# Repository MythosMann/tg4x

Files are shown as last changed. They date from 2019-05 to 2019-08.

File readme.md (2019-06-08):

Prototypes
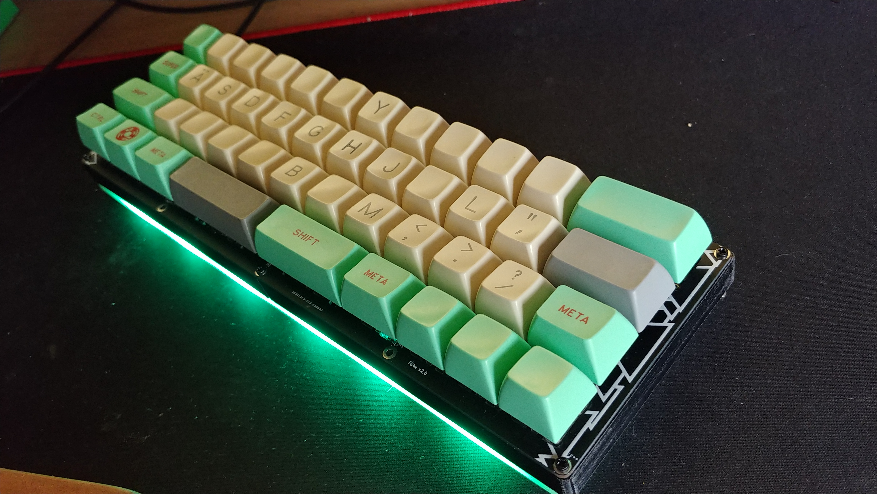
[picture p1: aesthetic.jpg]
3d printed midlayer and acrylic bottom

Picture of the Current Prototype
Nude
PCB
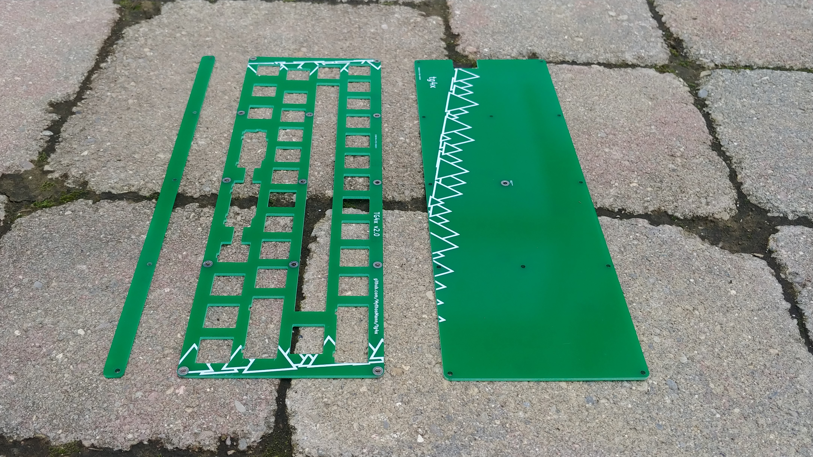
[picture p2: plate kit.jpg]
Plate Kit


Last gen prototype using tg3 as a base.
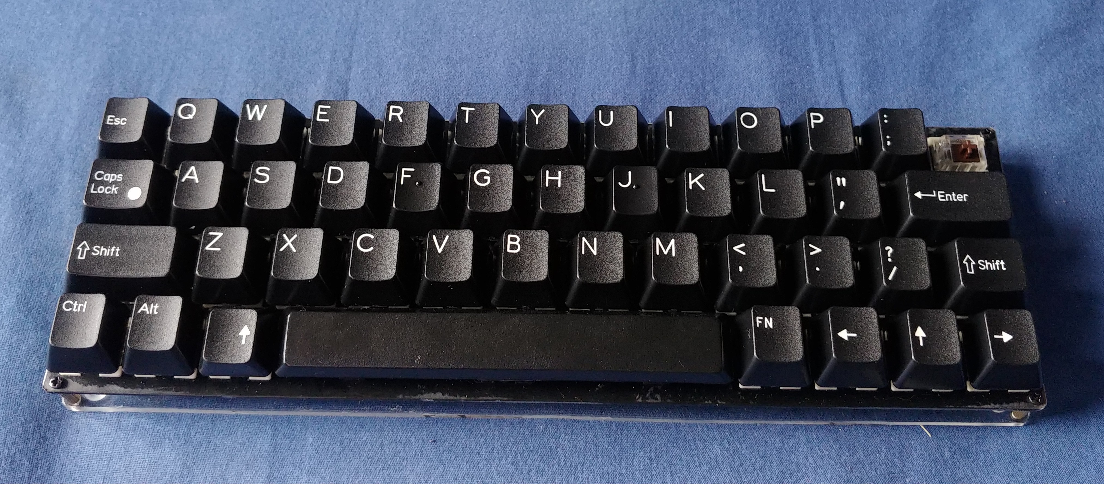
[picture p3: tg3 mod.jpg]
tg3 mod


## Summary:
Basically an open-source, cheap 45% keyboard.  You can use parts from a tg3 keyboard for maximum cheap, or use standard ansi keycaps.

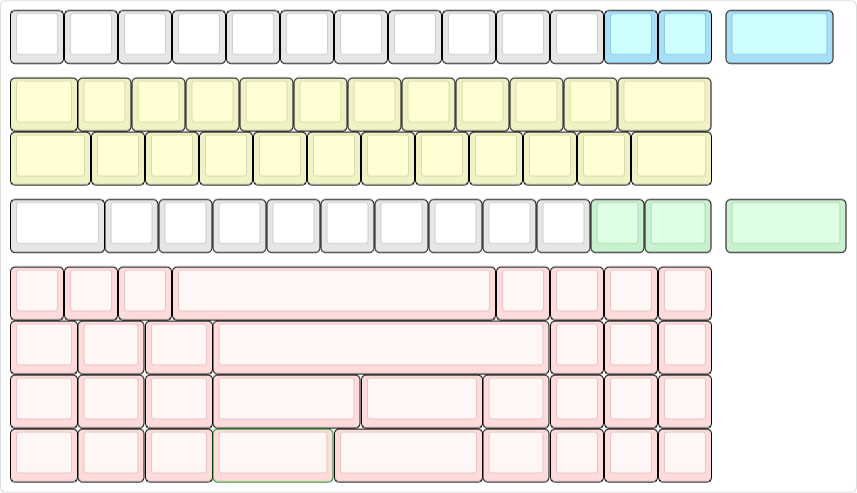
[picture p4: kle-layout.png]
KLE layout


## Features:
*Staggered 45%, meaning an extra column over standard 40%.

*Multiple supported layouts, including split spacebar.

*QMK compatible.

*Driven by pro micro, easily programmable and cheap.

*Uses standard sized keycaps that you could find in any set.

*RGB underglow, used for layer indication and caps lock.

*Design for pcb plates.

*Optional 6° angle.

## The base (TG3):
You can either use a tg3 as the base for this, or use your own parts.  The advantages of using the tg3 are price and sturdy-ness.  With a tg3, you can get Cherry blacks, uniform dcs keycaps, a steel mounting plate, and an aluminum back plate, all for $15-25.  If you were to buy the absolute cheapest keycap set ($6-8), the cheapest switches ($5 for 50), an fr4 or aluminum plate (~$10-15), and use a scrap of something for the back plate, it'd cost a bit more, and you'd be dealing with low quality parts. Granted, it takes some work to desolder and mod the tg3.

[Ebay listing where I've bought several](http://www.ebay.com/itm/132873035023)
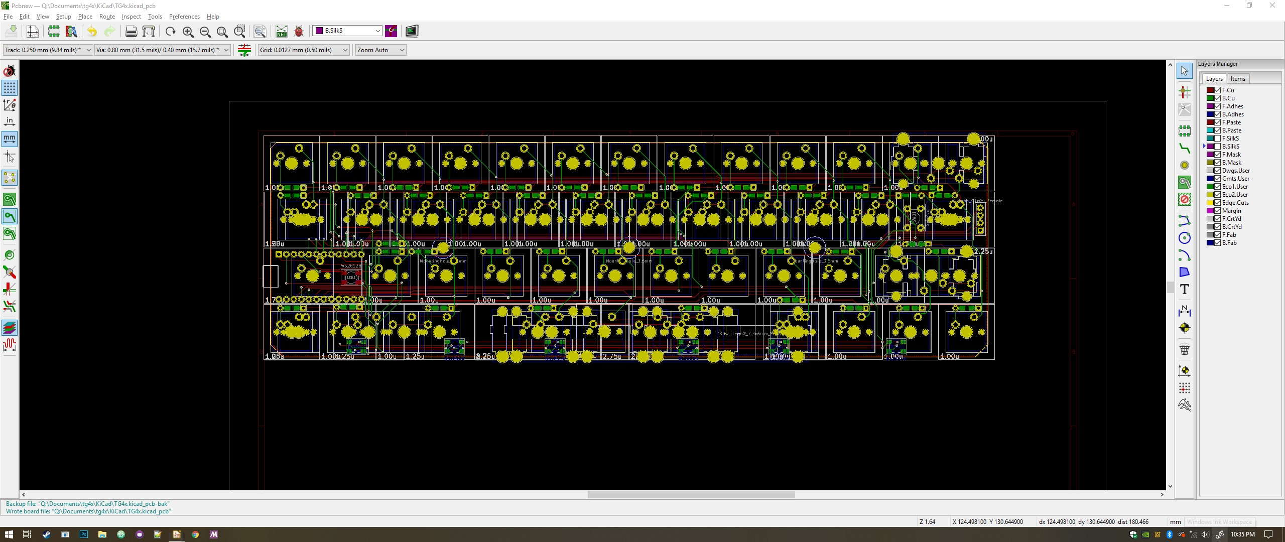
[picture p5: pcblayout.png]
Picture of the PCB


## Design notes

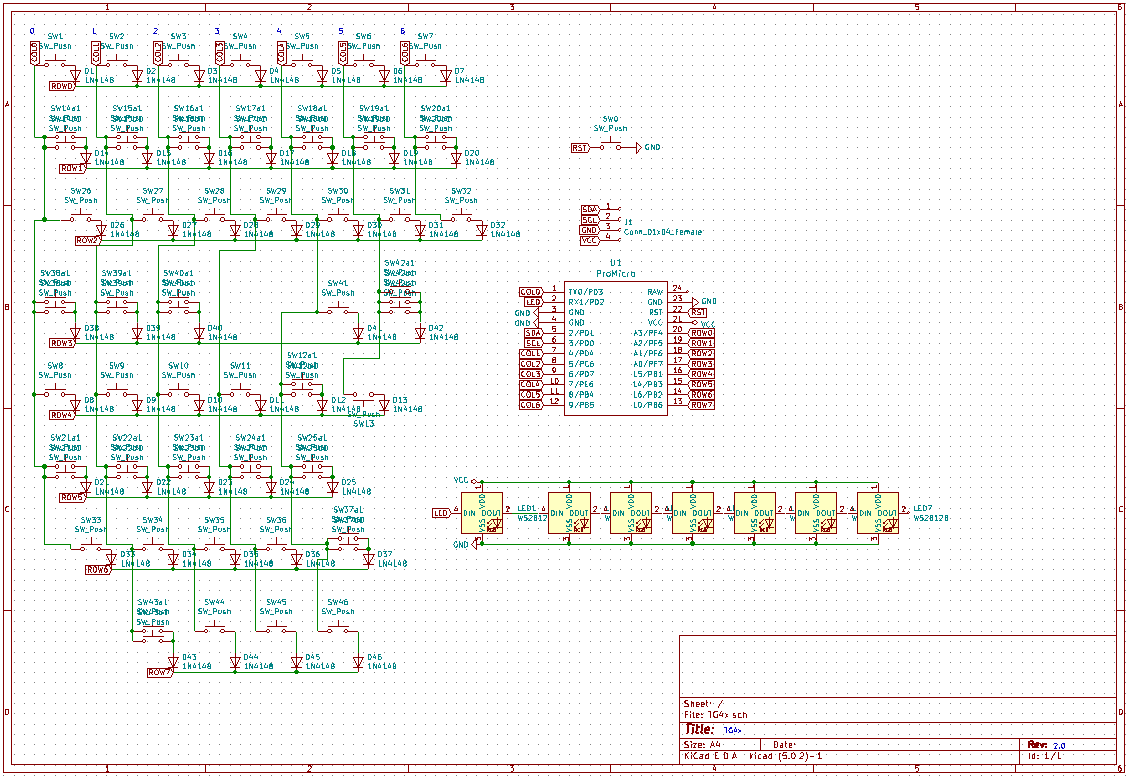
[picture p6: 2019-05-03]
Schematic.png

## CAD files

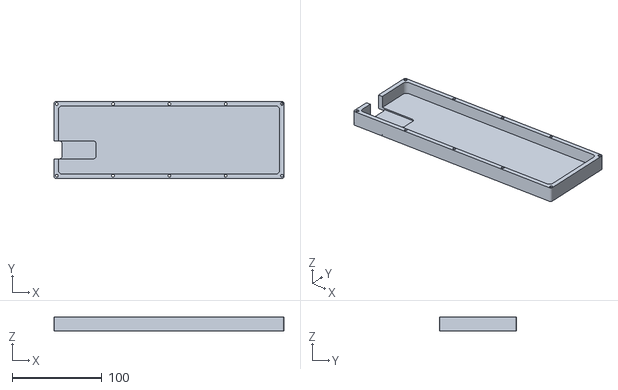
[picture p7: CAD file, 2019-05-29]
2d-3d stuff/tg4x case 3dp.stl
257.0 x 86.0 x 16.0

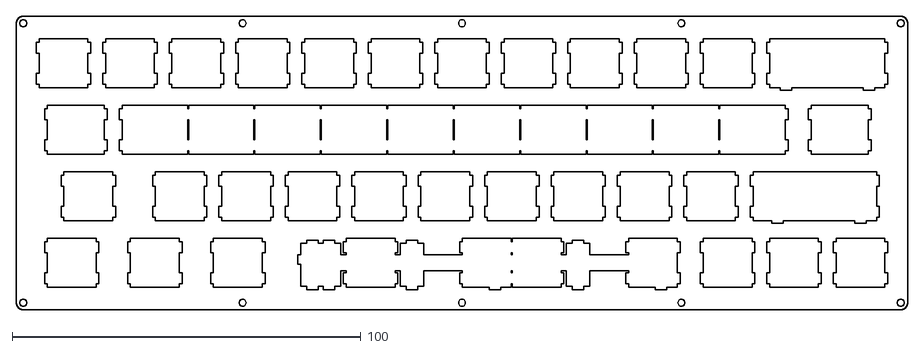
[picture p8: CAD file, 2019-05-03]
KiCad/switchplate.dxf
255.7 x 84.2

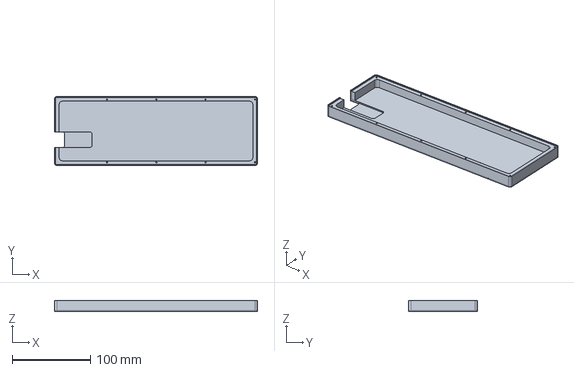
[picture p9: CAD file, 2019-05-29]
2d-3d stuff/tg4x case nomid.step
259.0 x 88.0 x 13.5 mm

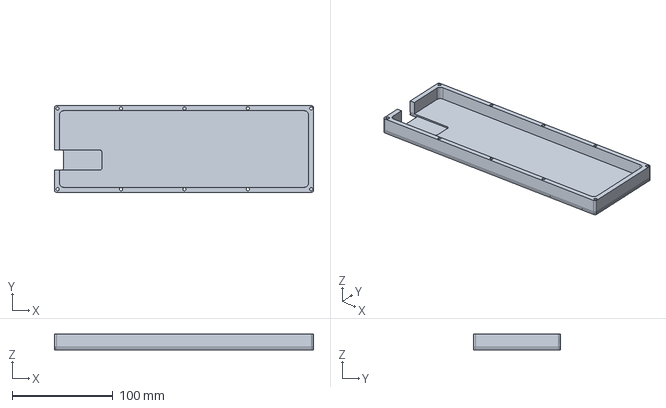
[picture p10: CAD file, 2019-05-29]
2d-3d stuff/tg4x_swillkb.step
257.0 x 86.0 x 15.5 mm

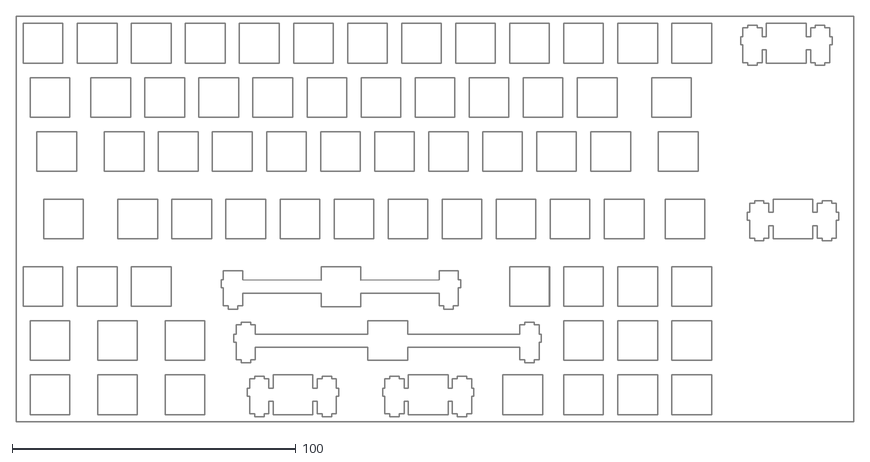
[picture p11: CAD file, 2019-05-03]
2d-3d stuff/tg4x_all_layout.dxf
295.3 x 142.9

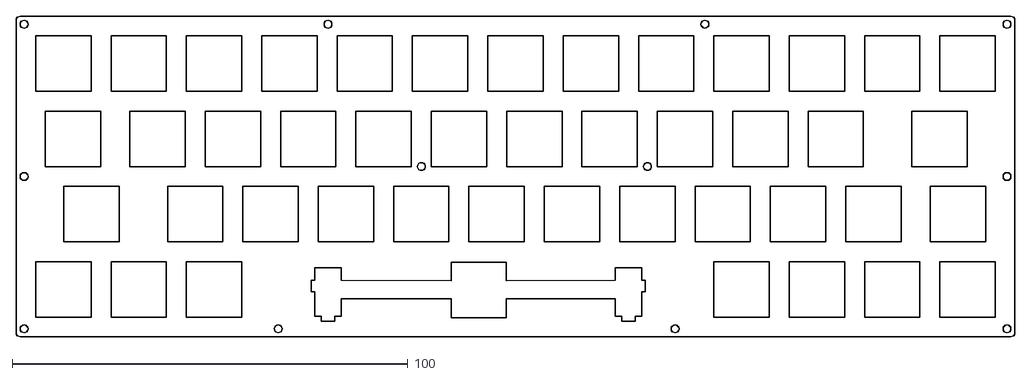
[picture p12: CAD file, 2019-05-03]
2d-3d stuff/switch_plate.dxf
252.5 x 81.0

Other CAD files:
2d-3d stuff/tg4x case.step
2d-3d stuff/tg4x case.stl
2d-3d stuff/tg4x_swillkb.stl

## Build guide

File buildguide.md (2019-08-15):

## Build Guide

Alrighty, so you got your tg4x stuff, but don’t know how to put it together.  I’ve finally gotten around to making this build guide, so now you’re covered.  Inside your box (depending on what you ordered), you should have 2 packages.
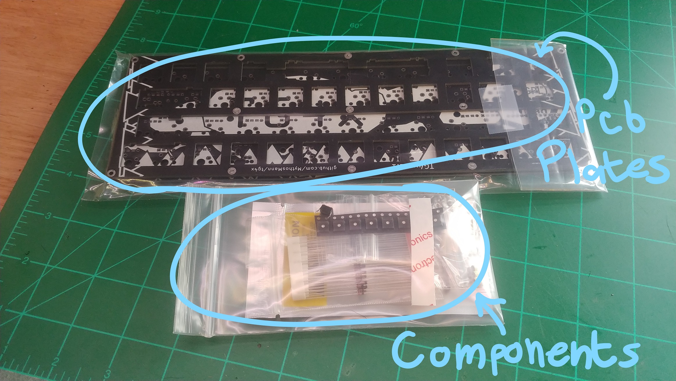
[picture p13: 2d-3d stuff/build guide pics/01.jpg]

One bag is the plates, and the pcb.  The other is your assembly kit, which contains all of the other pieces and components you need.
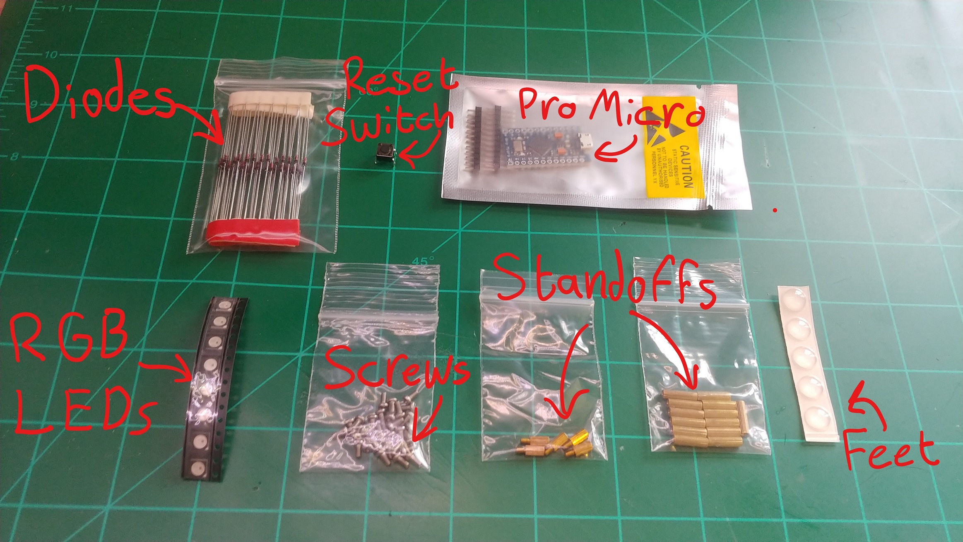
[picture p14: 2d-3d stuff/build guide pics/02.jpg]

Inside your assembly kit, you’ll find 50x diodes, a reset switch, a pro micro, 8x ws2812b rgb leds, ~28x screws, 5x 5mm male/female standoffs, 13x 11mm female/female standoffs, and some little rubber feet.
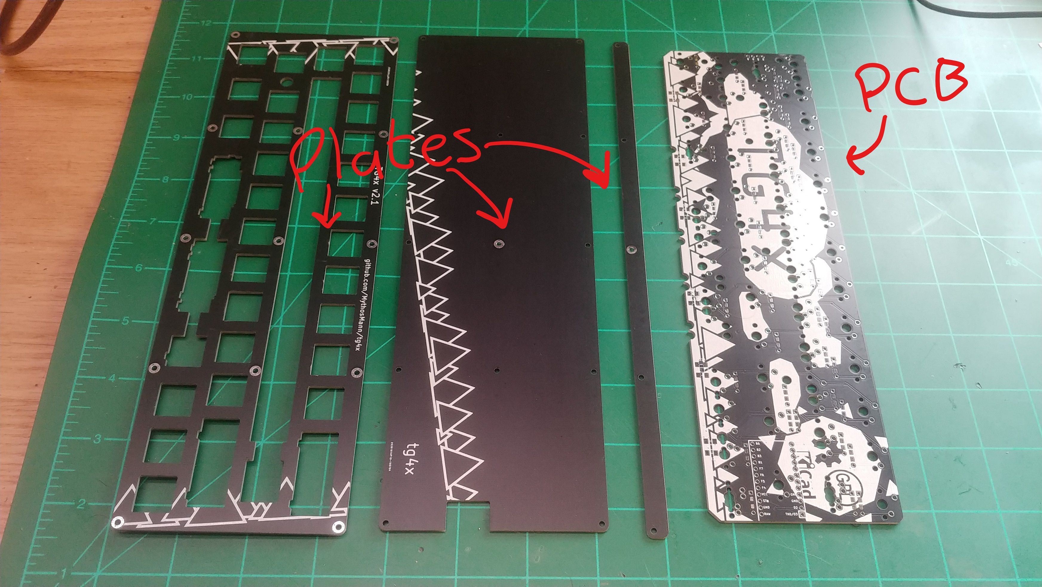
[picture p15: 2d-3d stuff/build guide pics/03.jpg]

In the other package, you’ll get a top plate, bottom plate, and a skinny little plate that you can use as a foot (to add a ~5 typing angle).  You’ll also get the pcb, where the magic happens.

 First thing you’ll want to do is bend all your diodes.  An easy way to do it consistently is to use your plates and pcb, put the diodes on top, and push all the legs down.  Then you’ve got to pull the paper off all the leads.  Next, you’re gonna put diodes in all of the diode holes.  It doesn’t matter if you put them on the top or bottom of the pcb, but make sure that they are oriented correctly.  You want the end with the black strip to go into the square holes.
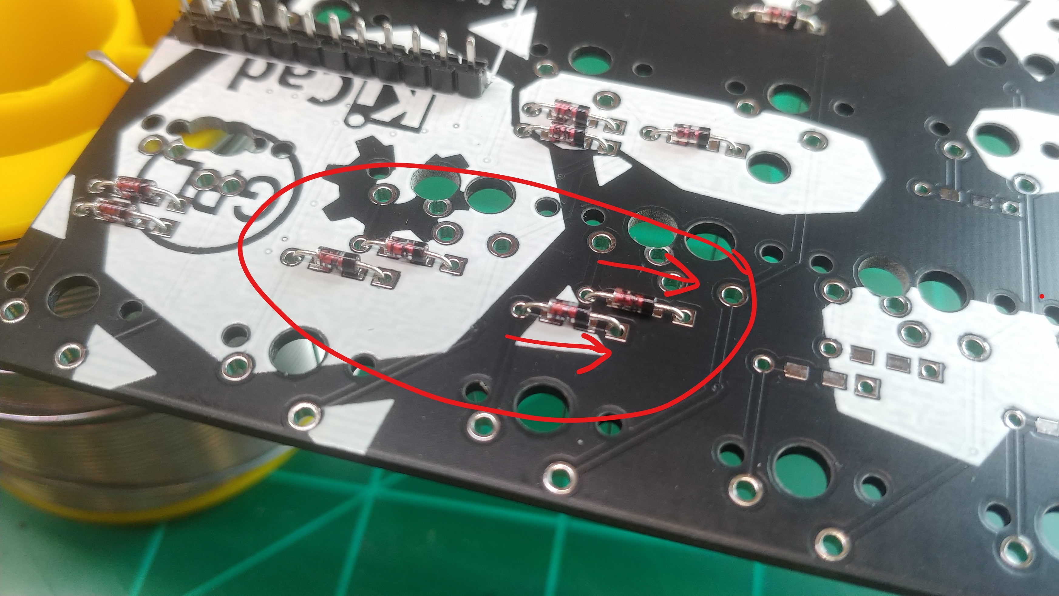
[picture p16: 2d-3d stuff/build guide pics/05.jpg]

The easiest way to install the diodes is to place them all in, then use masking tape to hold them in place.  Now you can flip the whole thing over, clip the legs off, and solder them all in.  I find it’s easier and looks cleaner if you clip the legs before soldering, but you could also solder first.
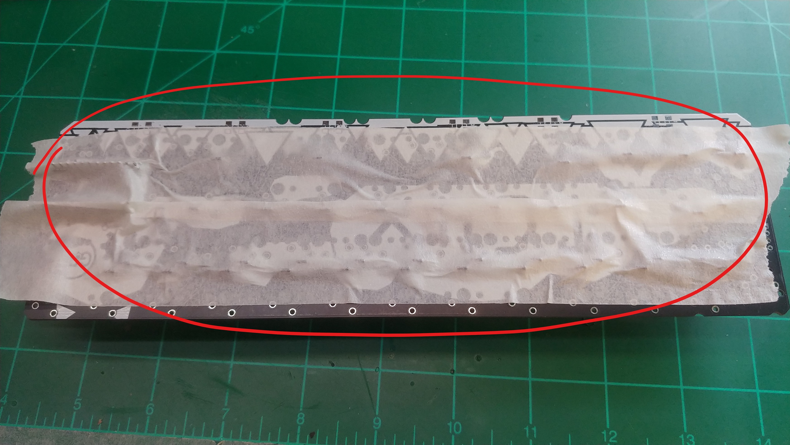
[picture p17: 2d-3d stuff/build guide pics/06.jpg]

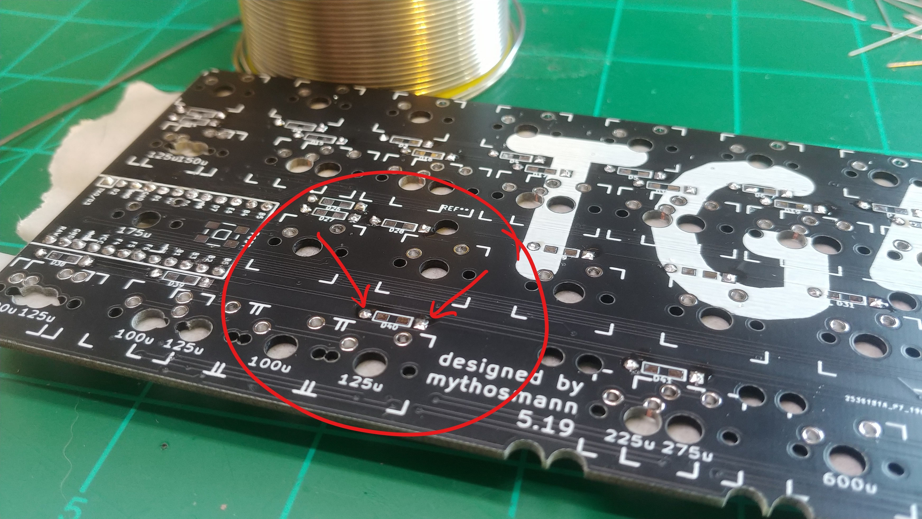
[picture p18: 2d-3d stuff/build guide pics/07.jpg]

Next, you want to solder in the headers for the pro micro.  You want them on the bottom of the pcb, which is the side with the big fancy graphic.  Don’t solder the pro micro on yet!  If you do, it’s gonna be really hard to solder the switches later.  I’d put the short end of the headers away from the pcb, with the long legs going through.  Then clip them flush with pcb.
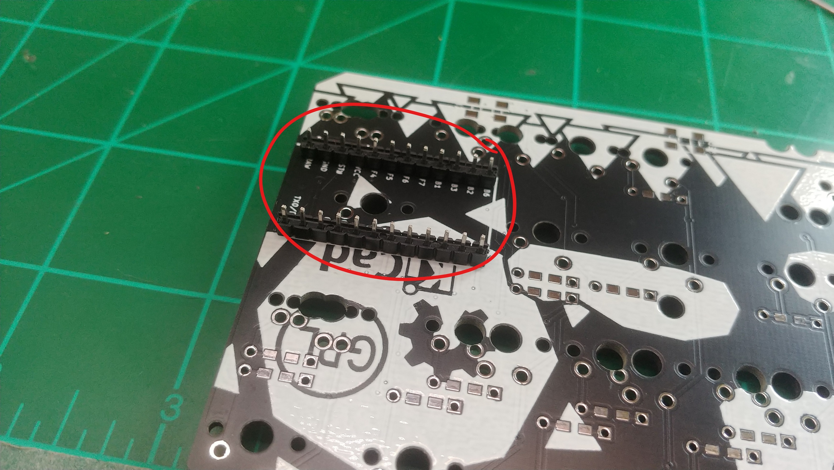
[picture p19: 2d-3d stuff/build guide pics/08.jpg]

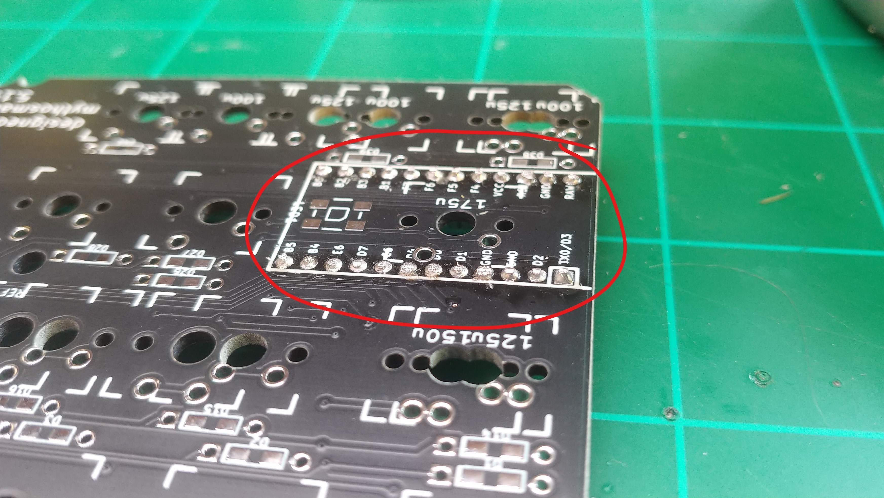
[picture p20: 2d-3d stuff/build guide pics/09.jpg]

Next, solder on the leds.  There’s one on the top of the pcb, and six on the bottom.  For the one on top, you want to make sure that the white corner is facing the left side of the pcb.  The leds on the bottom of the pcb all face down to the right, except for the one on the far right, which faces the other way.
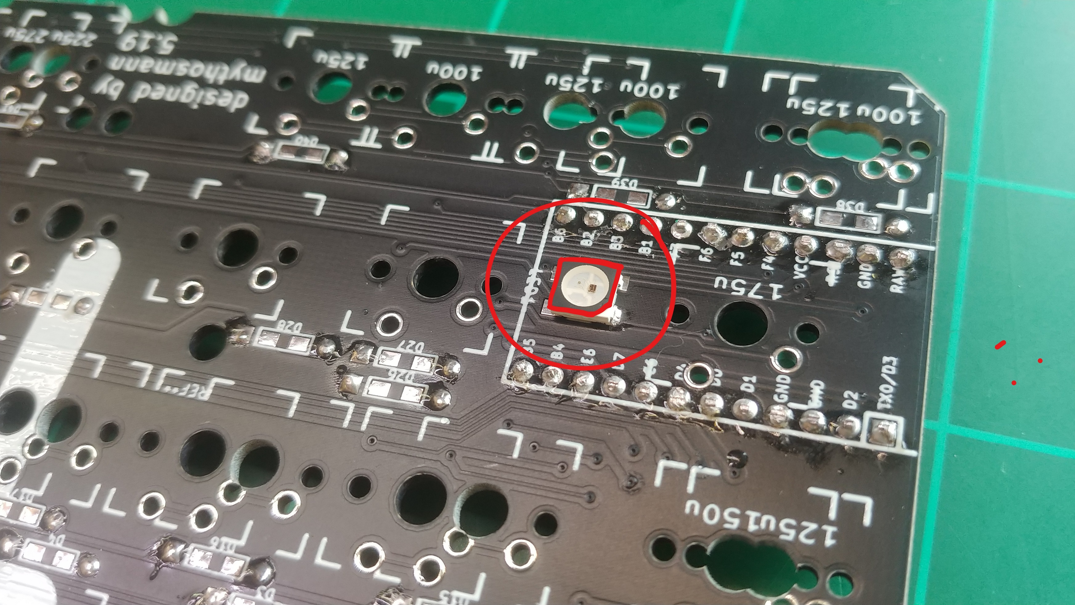
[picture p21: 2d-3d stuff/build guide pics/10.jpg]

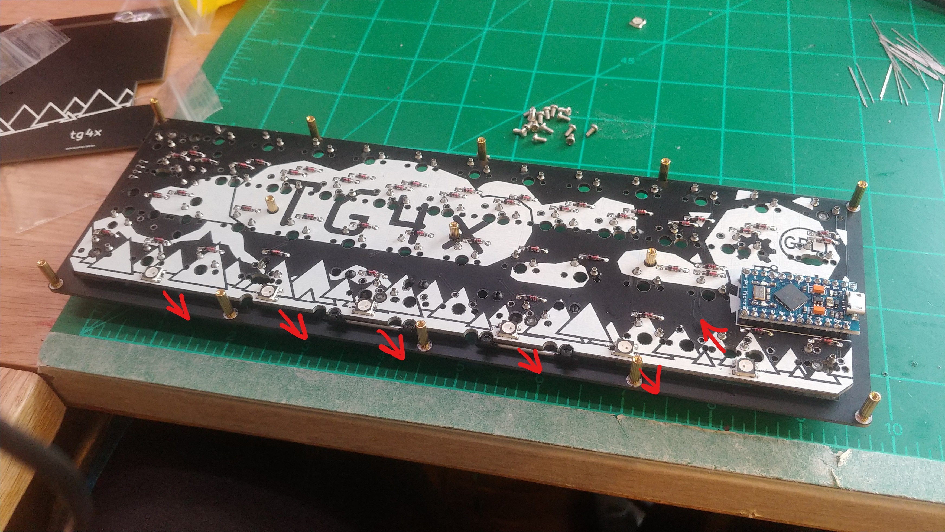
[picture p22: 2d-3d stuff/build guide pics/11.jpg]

If you have mill-max sockets, you’ll want to solder them in now.  I solder them just like diodes, so I’ll put them all in, tape over them, then solder them from the underside.
If you don’t have the sockets, skip over this step.
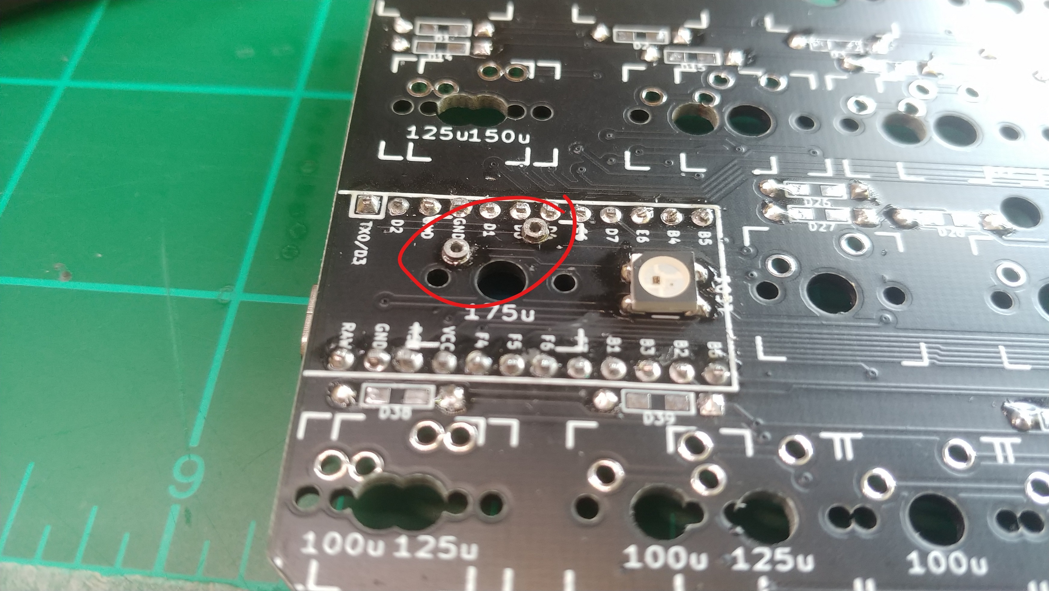
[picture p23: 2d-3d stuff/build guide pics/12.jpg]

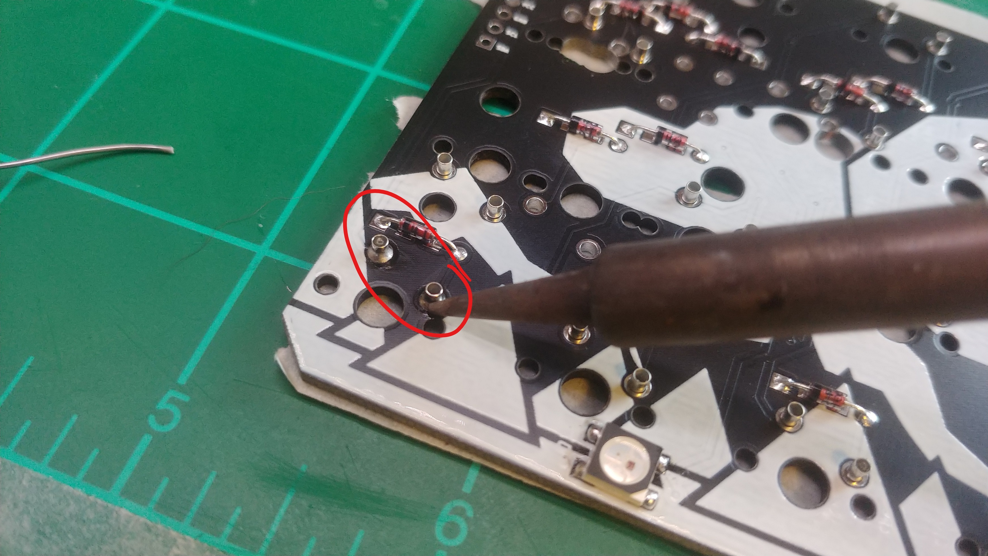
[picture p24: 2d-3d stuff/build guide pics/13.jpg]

Make sure you put the stabilizers in before you start to add the switches.  Put switches in each of the corners of the top plate, then fit it into the pcb.  I also like to put switches where the stabs are.  Solder those switches into the pcb.  Now it’ll be easier to fit the rest of the switches in, and solder them.  Of course, if you’re using mill-max sockets, there’s no need to solder the switches.
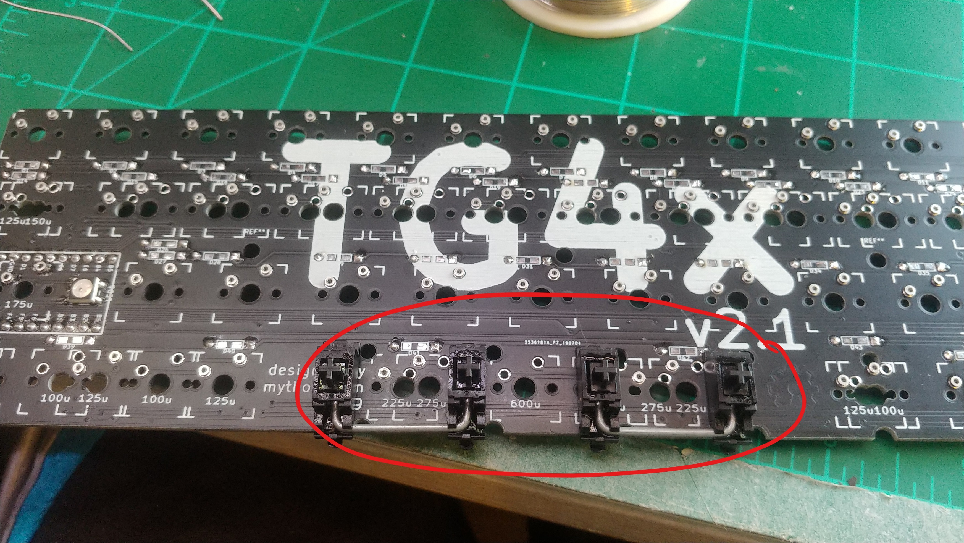
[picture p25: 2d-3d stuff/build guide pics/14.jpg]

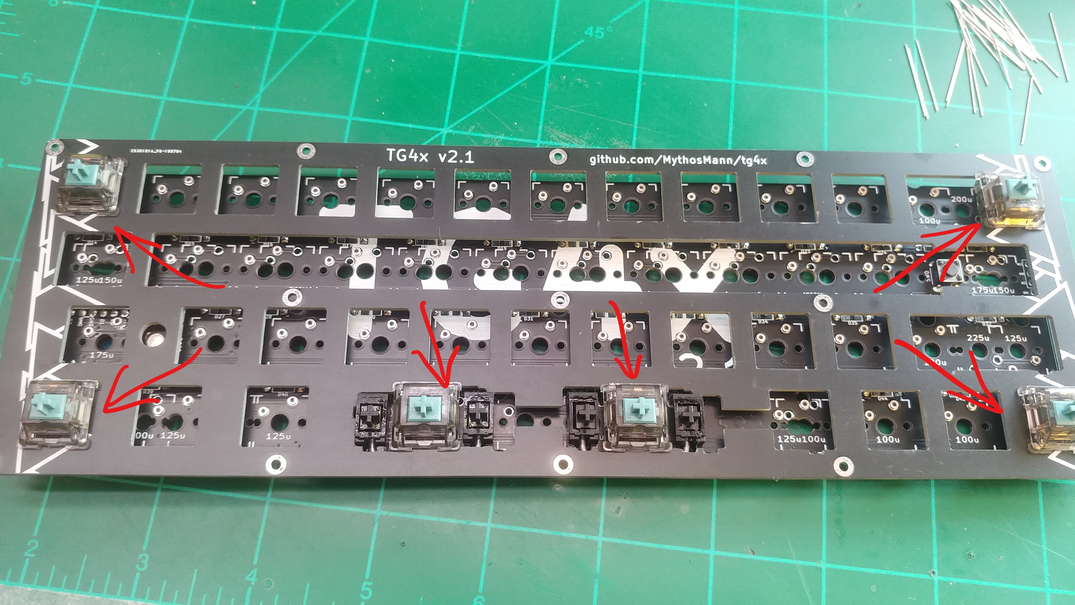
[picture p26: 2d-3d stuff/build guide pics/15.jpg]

After you’ve got all the switches installed, screw in all of the standoffs to the top plate.  There are 13 in total.  Put the bottom plate on, and screw it down.
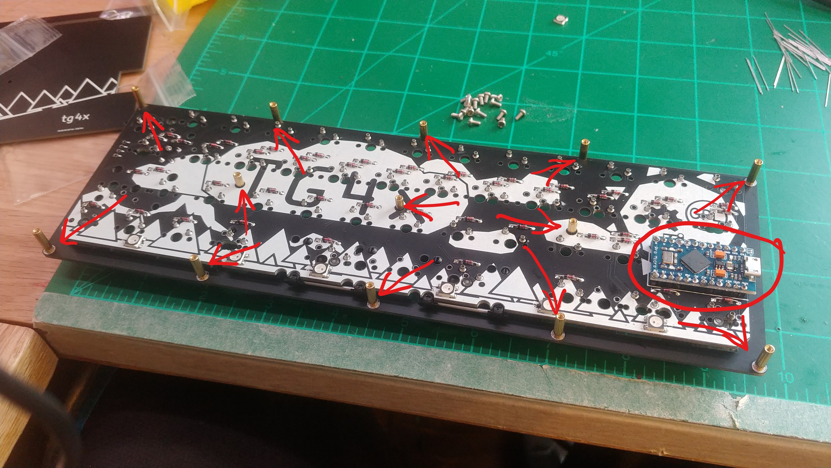
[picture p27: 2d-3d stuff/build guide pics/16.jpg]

If you want a bit of angle, use the 5mm standoffs in place of the screws on the top row.  Then, put the small plate on, and screw it in.
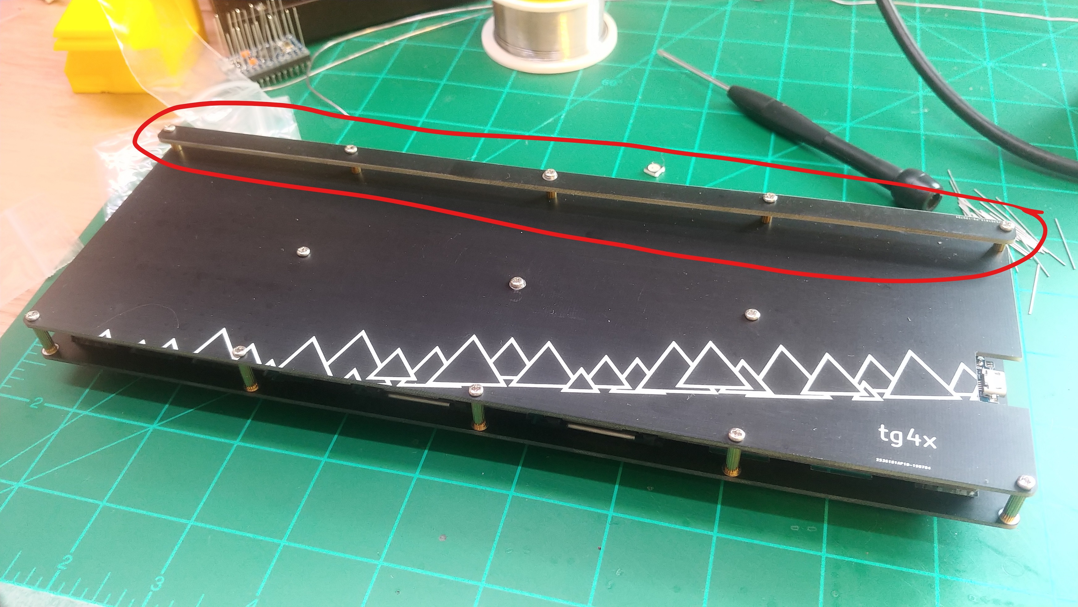
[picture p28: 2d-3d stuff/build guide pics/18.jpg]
 
Now all you’ve got to do is stick on some rubber feet, and find your keycaps.
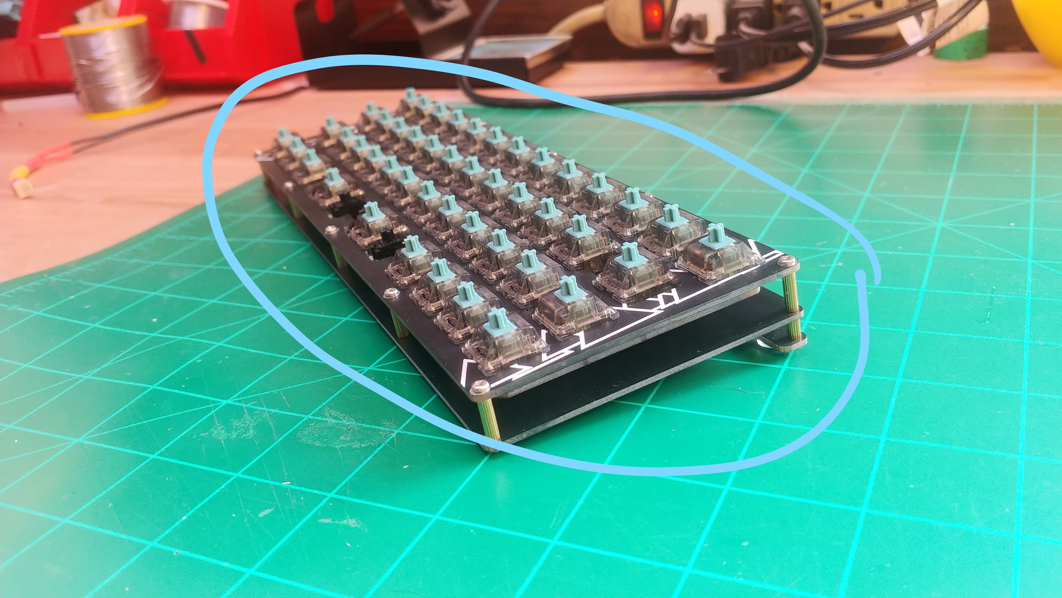
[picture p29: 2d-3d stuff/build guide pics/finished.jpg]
finished


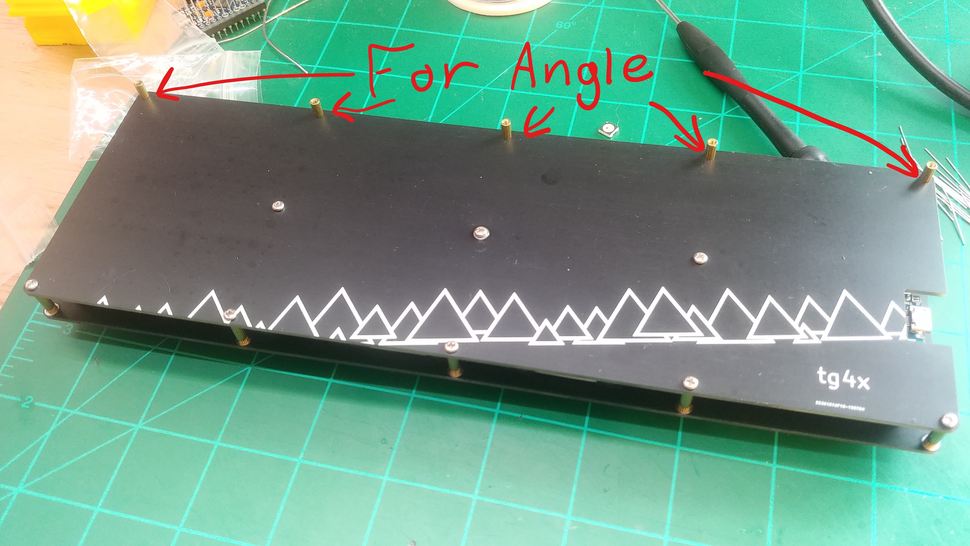
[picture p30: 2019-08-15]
2d-3d stuff/build guide pics/17.jpg

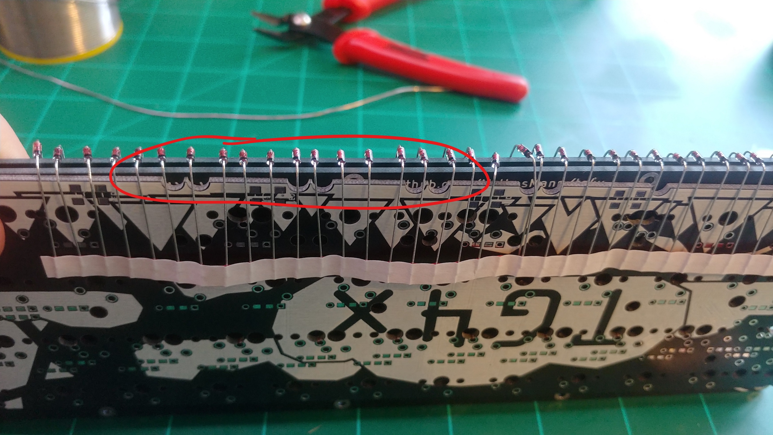
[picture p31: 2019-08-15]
2d-3d stuff/build guide pics/04.jpg

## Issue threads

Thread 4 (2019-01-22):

Footprint too big

MythosMann, 2019-01-22:

Closed 2019-01-23.

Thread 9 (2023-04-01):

Error when compiling qmk

sunmorgus, 2023-04-01:
I'm getting all sorts of errors when attempting to compile changes to QMK, and seem to have gotten the keyboard set back to some sort of default that just doesn't have keys mapped properly at _all_... below is the error message I get when attempting to compile:

What I've done:
1. Setup qmk properly (it works just fine for my Keychron V8)
1. Cloned the `tg4x` folder from the `qmk_firmware/keyboards` directory, and copied the `qmk_firmware/keyboards/tg4x` over to my `qmk_firmware/keyboards` home
2. Run both `qmk compile -kb tg4x -km default` and `make tg4x/rev21:default` and got the below errors

**Running qmk compile**
```
➜  ~/qmk_firmware git:(master) ✗ qmk compile -kb tg4x -km default
Ψ Compiling keymap with gmake --jobs=1 tg4x:default

QMK Firmware 0.20.3
☒ tg4x: Layout "LAYOUT" has no "matrix" definition in either "info.json" or "<keyboard>.h"!
☒ 'matrix_size'
Traceback (most recent call last):
  File "/home/sunmorgus/.local/lib/python3.10/site-packages/milc/milc.py", line 528, in __call__
    return self.__call__()
  File "/home/sunmorgus/.local/lib/python3.10/site-packages/milc/milc.py", line 533, in __call__
    return self._subcommand(self)
  File "/home/sunmorgus/qmk_firmware/lib/python/qmk/decorators.py", line 27, in wrapper
    return func(*args, **kwargs)
  File "/home/sunmorgus/qmk_firmware/lib/python/qmk/cli/list/layouts.py", line 21, in list_layouts
    info_data = info_json(cli.config.list_layouts.keyboard)
  File "/home/sunmorgus/qmk_firmware/lib/python/qmk/info.py", line 148, in info_json
    info_data = _extract_led_config(info_data, str(keyboard))
  File "/home/sunmorgus/qmk_firmware/lib/python/qmk/info.py", line 670, in _extract_led_config
    cols = info_data['matrix_size']['cols']
KeyError: 'matrix_size'
Making tg4x with keymap default

☒ tg4x: Layout "LAYOUT" has no "matrix" definition in either "info.json" or "<keyboard>.h"!
☒ 'matrix_size'
Traceback (most recent call last):
  File "/home/sunmorgus/.local/lib/python3.10/site-packages/milc/milc.py", line 528, in __call__
    return self.__call__()
  File "/home/sunmorgus/.local/lib/python3.10/site-packages/milc/milc.py", line 533, in __call__
    return self._subcommand(self)
  File "/home/sunmorgus/qmk_firmware/lib/python/qmk/cli/generate/rules_mk.py", line 59, in generate_rules_mk
    kb_info_json = dotty(info_json(cli.args.keyboard))
  File "/home/sunmorgus/qmk_firmware/lib/python/qmk/info.py", line 148, in info_json
    info_data = _extract_led_config(info_data, str(keyboard))
  File "/home/sunmorgus/qmk_firmware/lib/python/qmk/info.py", line 670, in _extract_led_config
    cols = info_data['matrix_size']['cols']
KeyError: 'matrix_size'

 *                                                                                                     [ERRORS]

builddefs/build_keyboard.mk:196: *** Platform not defined.  Stop.
Make finished with errors
gmake: *** [Makefile:392: tg4x:default] Error 1

```

**Running make**
```
➜  ~/qmk_firmware git:(master) ✗ make tg4x/rev21:default
QMK Firmware 0.20.3
☒ tg4x/rev21: Layout "LAYOUT" has no "matrix" definition in either "info.json" or "<keyboard>.h"!
☒ tg4x/rev21: DESCRIPTION in config.h is no longer a valid option and should be removed
☒ tg4x/rev21: DEBOUNCING_DELAY in config.h is no longer a valid option and should be replaced with DEBOUNCE
⚠ tg4x/rev21: UNUSED_PINS in config.h is deprecated and will be removed at a later date
⚠ tg4x/rev21: PRODUCT_ID in config.h is deprecated in favor of `usb.pid` in info.json and will be removed at a later date
⚠ tg4x/rev21: VENDOR_ID in config.h is deprecated in favor of `usb.vid` in info.json and will be removed at a later date
⚠ tg4x/rev21: PRODUCT in config.h is deprecated in favor of `keyboard_name` in info.json and will be removed at a later date
⚠ tg4x/rev21: MANUFACTURER in config.h is deprecated in favor of `manufacturer` in info.json and will be removed at a later date
⚠ tg4x/rev21: DEVICE_VER in config.h is deprecated in favor of `usb.device_version` in info.json and will be removed at a later date
☒ Invalid API data: tg4x/rev21: layouts: 'LAYOUT_TG3' is not valid under any of the given schemas
Making tg4x/rev21 with keymap default

☒ tg4x/rev21: Layout "LAYOUT" has no "matrix" definition in either "info.json" or "<keyboard>.h"!
☒ tg4x/rev21: DESCRIPTION in config.h is no longer a valid option and should be removed
☒ tg4x/rev21: DEBOUNCING_DELAY in config.h is no longer a valid option and should be replaced with DEBOUNCE
⚠ tg4x/rev21: UNUSED_PINS in config.h is deprecated and will be removed at a later date
⚠ tg4x/rev21: PRODUCT_ID in config.h is deprecated in favor of `usb.pid` in info.json and will be removed at a later date
⚠ tg4x/rev21: VENDOR_ID in config.h is deprecated in favor of `usb.vid` in info.json and will be removed at a later date
⚠ tg4x/rev21: PRODUCT in config.h is deprecated in favor of `keyboard_name` in info.json and will be removed at a later date
⚠ tg4x/rev21: MANUFACTURER in config.h is deprecated in favor of `manufacturer` in info.json and will be removed at a later date
⚠ tg4x/rev21: DEVICE_VER in config.h is deprecated in favor of `usb.device_version` in info.json and will be removed at a later date
☒ Invalid API data: tg4x/rev21: layouts: 'LAYOUT_TG3' is not valid under any of the given schemas

 *                                                                                                     [ERRORS]

builddefs/build_keyboard.mk:196: *** Platform not defined.  Stop.
Make finished with errors
make: *** [Makefile:392: tg4x/rev21:default] Error 1
```

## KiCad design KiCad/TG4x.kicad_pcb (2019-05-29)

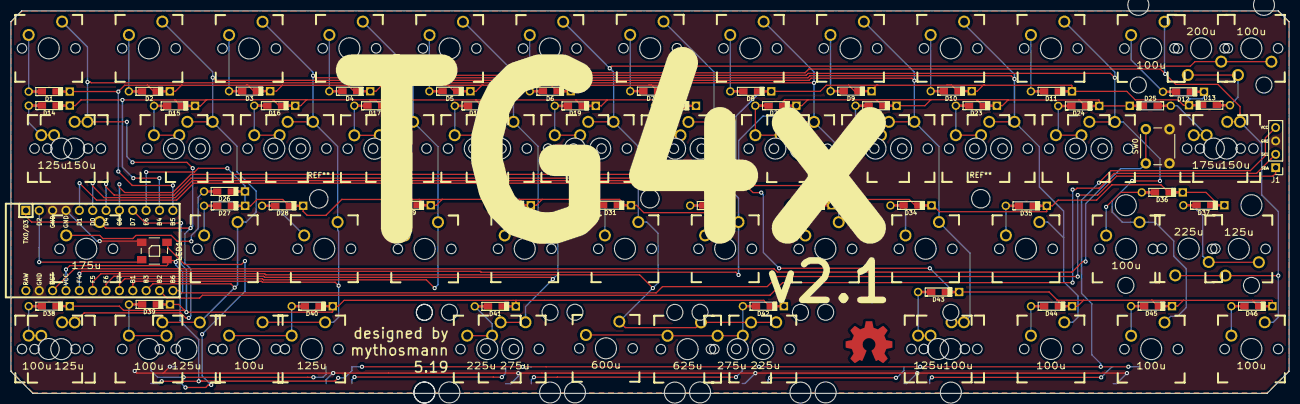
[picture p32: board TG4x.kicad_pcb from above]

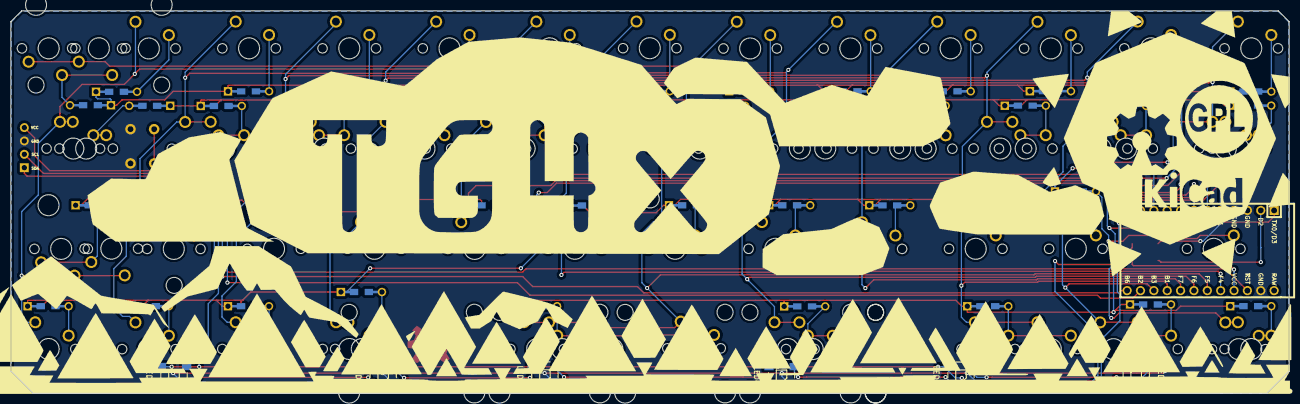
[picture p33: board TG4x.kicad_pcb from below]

Board: 2 copper layers, 243.0 x 72.7 mm, 124 parts (7 on the bottom side), 73 nets.

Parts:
100u, 100u#2, 100u#3, 100u#4, 100u#5, 100u#6, 100u#7, 100u#8, 100u#9, 100u#10, 125u, 600u: SW_Push; MX_PCB_100H
125u#2, 125u#3, 125u#4, 125u#5, 125u#6: SW_Push; MX_PCB_125H
150u, 175u#2: SW_Push; MX_PCB_150H
150u#2, 175u: SW_Push; MX_PCB_175H
200u: SW_Push; MX_PCB_200H
225u, 225u#2, 225u#3: SW_Push; MX_PCB_225H
275u, 275u#2: SW_Push; MX_PCB_275H
625u: SW_Push; MX_PCB_625H
D1, D2, D3, D4, D5, D6, D7, D8, D9, D10, D11, D12, D13, D14, D15, D16, D17, D18, D19, D20, D21, D22, D23, D24, D25, D26, D27, D28, D29, D30, D31, D32, D33, D34, D35, D36, D37, D38, D39, D40, D41, D42, D43, D44, D45, D46: 1N4148; Diode-dual
J1: Conn_01x04_Female; PinHeader_1x04_P2.54mm_Vertical
LED1, LED2, LED3, LED4, LED5, LED6, LED7: WS2812B
SW0: SW_Push; SW_PUSH_6mm
SW1, SW2, SW3, SW4, SW5, SW6, SW7, SW8, SW9, SW10, SW11, SW15, SW15b1, SW16, SW16b1, SW17, SW17b1, SW18, SW18b1, SW19, SW19b1, SW20, SW20b1, SW21, SW21b1, SW22, SW22b1, SW23, SW23b1, SW24, SW24b1, SW27, SW28, SW29, SW30, SW31, SW32, SW33, SW34, SW35: SW_Push; MX_PCB_100H
U1: ProMicro; ArduinoProMicro

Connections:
COL0: 100u#6.1, 125u#2.1, 125u#4.1, 150u.1, 175u.1, SW1.1, SW8.1, SW21.1, SW21b1.1, SW33.1, U1.1
COL1: 100u#7.1, 100u#9.1, 125u.1, 125u#5.1, SW2.1, SW9.1, SW15.1, SW15b1.1, SW22.1, SW22b1.1, SW27.1, SW34.1, U1.15
COL2: 100u#2.1, 100u#8.1, 125u#6.1, SW3.1, SW10.1, SW16.1, SW16b1.1, SW23.1, SW23b1.1, SW28.1, SW35.1, U1.16
COL3: 100u.1, 100u#3.1, SW4.1, SW11.1, SW17.1, SW17b1.1, SW24.1, SW24b1.1, SW29.1, U1.17
COL4: 100u#4.1, 100u#5.1, 125u#3.1, 150u#2.1, 175u#2.1, 225u.1, 225u#2.1, 275u#2.1, SW5.1, SW18.1, SW18b1.1, SW30.1, U1.18
COL5: 100u#10.2, 200u.2, 225u#3.1, 275u.1, 600u.1, 625u.1, SW6.1, SW19.1, SW19b1.1, SW31.1, U1.19
COL6: SW7.1, SW20.1, SW20b1.1, SW32.1, U1.20
GND: J1.3, LED1.3, LED2.3, LED3.3, LED4.3, LED5.3, LED6.3, LED7.3, SW0.2, U1.3, U1.4, U1.23
LED: LED1.4, U1.2
unnamed: D1.2, SW1.2
unnamed: D2.2, SW2.2
unnamed: D3.2, SW3.2
unnamed: D4.2, SW4.2
unnamed: D5.2, SW5.2
unnamed: D6.2, SW6.2
unnamed: D7.2, SW7.2
unnamed: D8.2, SW8.2
unnamed: D9.2, SW9.2
unnamed: D10.2, SW10.2
unnamed: D11.2, SW11.2
unnamed: 100u#5.2, D12.2
unnamed: 100u#10.1, 200u.1, D13.2
unnamed: 125u#2.2, 150u.2, D14.2
unnamed: D15.2, SW15.2, SW15b1.2
unnamed: D16.2, SW16.2, SW16b1.2
unnamed: D17.2, SW17.2, SW17b1.2
unnamed: D18.2, SW18.2, SW18b1.2
unnamed: D19.2, SW19.2, SW19b1.2
unnamed: D20.2, SW20.2, SW20b1.2
unnamed: D21.2, SW21.2, SW21b1.2
unnamed: D22.2, SW22.2, SW22b1.2
unnamed: D23.2, SW23.2, SW23b1.2
unnamed: D24.2, SW24.2, SW24b1.2
unnamed: 150u#2.2, 175u#2.2, D25.2
unnamed: 175u.2, D26.2
unnamed: D27.2, SW27.2
unnamed: D28.2, SW28.2
unnamed: D29.2, SW29.2
unnamed: D30.2, SW30.2
unnamed: D31.2, SW31.2
unnamed: D32.2, SW32.2
unnamed: D33.2, SW33.2
unnamed: D34.2, SW34.2
unnamed: D35.2, SW35.2
unnamed: 100u.2, D36.2
unnamed: 125u#3.2, 225u.2, D37.2
unnamed: 100u#6.2, 125u#4.2, D38.2
unnamed: 100u#7.2, 125u#5.2, D39.2
unnamed: 100u#8.2, 125u#6.2, D40.2
unnamed: 225u#2.2, 275u#2.2, D41.2
unnamed: 225u#3.2, 275u.2, 600u.2, 625u.2, D42.2
unnamed: 100u#9.2, 125u.2, D43.2
unnamed: 100u#2.2, D44.2
unnamed: 100u#3.2, D45.2
unnamed: 100u#4.2, D46.2
unnamed: LED1.2, LED2.4
unnamed: LED2.2, LED3.4
unnamed: LED3.2, LED4.4
unnamed: LED4.2, LED5.4
unnamed: LED5.2, LED6.4
unnamed: LED6.2, LED7.4
ROW0: D1.1, D2.1, D3.1, D4.1, D5.1, D6.1, D7.1, U1.12
ROW1: D14.1, D15.1, D16.1, D17.1, D18.1, D19.1, D20.1, U1.11
ROW2: D26.1, D27.1, D28.1, D29.1, D30.1, D31.1, D32.1, U1.10
ROW3: D38.1, D39.1, D40.1, D41.1, D42.1, U1.9
ROW4: D8.1, D9.1, D10.1, D11.1, D12.1, D13.1, U1.8
ROW5: D21.1, D22.1, D23.1, D24.1, D25.1, U1.7
ROW6: D33.1, D34.1, D35.1, D36.1, D37.1, U1.6
ROW7: D43.1, D44.1, D45.1, D46.1, U1.5
RST: SW0.1, U1.22
SCL: J1.2, U1.14
SDA: J1.1, U1.13
VCC: J1.4, LED1.1, LED2.1, LED3.1, LED4.1, LED5.1, LED6.1, LED7.1, U1.21

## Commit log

2019-01-23 Added KiCad files for first revision.
    The KiCad Libraries, Schematic, pcb, and gerber files.
    [TG4x-B.Cu.gbl, TG4x-B.Mask.gbs, TG4x-B.SilkS.gbo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]
2019-01-23 organized all files together
    Put everything together locally, hopefully made things more organized.
    [TG4x-B.Cu.gbl, TG4x-B.Mask.gbs, TG4x-B.Paste.gbp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]
2019-01-23 Trying to organize lol
    [TG4x-B.Cu.gbl, TG4x-B.Mask.gbs, TG4x-B.Paste.gbp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]
2019-01-23 Shifted some diode footprints
    [TG4x.kicad_pcb]
2019-01-23 removed LED Sleep
2019-01-24 Update Pro micro footprint
    Now uses keebio's staggered footprint
    [TG4x.kicad_pcb, TG4x.sch]
2019-01-24 Changed image files
    [TG4x.kicad_pcb]
2019-01-25 Added .dxf and .ai for plates
    [bottom_plate.dxf, switch_plate.dxf]
2019-01-25 Added middle standoff holes
    [TG4x.kicad_pcb, bottom_plate.dxf, switch_plate.dxf]
2019-01-27 fixed mouting holes
    [TG4x-B.Cu.gbl, TG4x-B.Mask.gbs, TG4x-B.SilkS.gbo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]
2019-01-29 added silkscreen
    [TG4x.kicad_pcb]
2019-01-29 added mounting holes, fixed traces, updated gerbers
    [TG4x-B.Cu.gbl, TG4x-B.Mask.gbs, TG4x-B.SilkS.gbo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]
2019-01-29 Adding Tap Dance Support to qmk files.
    [TG4x.kicad_pcb]
2019-01-29 updated keymap, re-enabled LEDs
2019-01-29 updated pcb graphic
    [TG4x.kicad_pcb]
2019-01-29 pcb graphics
    [TG4x.kicad_pcb]
2019-01-29 changed thumbs
    [TG4x.kicad_pcb]
2019-01-30 updated gerbers, switch plate files
    [TG4x-B.Cu.gbl, TG4x-B.Mask.gbs, TG4x-B.SilkS.gbo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]
2019-01-30 new render, updated case files
2019-02-01 changed footprints to 5 pin
    [TG4x.kicad_pcb]
2019-02-01 Fixed traces for 5 pin
    [TG4x.kicad_pcb]
2019-02-01 Updated gerbers for 5 pin
    [TG4x-B.Cu.gbl, TG4x-B.Mask.gbs, TG4x-B.SilkS.gbo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]
2019-02-05 Fixed traces, leds
    moved some of the traces that were too close to holes, moved leds out from under holes
    [TG4x.kicad_pcb]
2019-02-06 updated to staggered pro micro footprint
    [TG4x.kicad_pcb]
2019-02-08 moved spacebar switch footprint
    [TG4x.kicad_pcb, bottom_plate.dxf, switch_plate.dxf]
2019-02-08 moved left hand diodes in
    [TG4x.kicad_pcb]
2019-02-08 added clearance for standoffs
    [TG4x.kicad_pcb, switch_plate.dxf]
2019-02-08 finished adding standoff clearance
    [TG4x.kicad_pcb]
2019-02-09 Changing pcb Graphic
    [TG4x-B.Cu.gbl, TG4x-B.Mask.gbs, TG4x-B.SilkS.gbo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]
2019-02-09 Organized image files, finished graphic
    [TG4x-B.Cu.gbl, TG4x-B.Mask.gbs, TG4x-B.SilkS.gbo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]
2019-02-10 Fixed LED Polaarity, uppdated to v1.2
    [TG4x.kicad_pcb, TG4x.sch]
2019-02-11 Updated graphic and thummbnails
    [TG4x.kicad_pcb, TG4x.sch]
2019-02-11 slightly changed edge cut
    [TG4x-B.Cu.gbl, TG4x-B.Mask.gbs, TG4x-B.SilkS.gbo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]
2019-02-19 trimmed top and bottom.
    [TG4x.kicad_pcb]
2019-02-19 scaled graphic to new pcb
    [TG4x.kicad_pcb]
2019-02-19 Update PCB_forest graphic.psd
2019-02-19 shrunk column labelling
    [TG4x.kicad_pcb]
2019-02-19 removed switch labels from f.silk
    [TG4x.kicad_pcb]
2019-02-24 updated gerber files
    [TG4x-B.Cu.gbl, TG4x-B.Mask.gbs, TG4x-B.SilkS.gbo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]
2019-02-24 updated gerbers, started on platge stencil
    [TG4x-B.Cu.gbl, TG4x-B.Mask.gbs, TG4x-B.SilkS.gbo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]
2019-02-24 gerbers again
    [TG4x-B.Cu.gbl, TG4x-B.Mask.gbs, TG4x-B.SilkS.gbo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]
2019-02-24 changed gerber settings
    [TG4x-B.Cu.gbr, TG4x-B.Mask.gbr, TG4x-B.SilkS.gbr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]
2019-02-25 updated gerbers once again
    [TG4x-B.Cu.gbr, TG4x-B.Mask.gbr, TG4x-B.SilkS.gbr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]
2019-02-27 updated gerbers
    [TG4x-B.Cu.gbr, TG4x-B.Mask.gbr, TG4x-B.SilkS.gbr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]
2019-03-18 added additional switch footprints to pcb
    [TG4x.kicad_pcb]
2019-03-20 moved sw3 footprint up
    [TG4x.kicad_pcb]
2019-03-20 moved sw3 up
    [TG4x.kicad_pcb]
2019-03-24 removed footprints
    [TG4x.kicad_pcb]
2019-03-25 cleared pcb, added switches to schematic
    [TG4x.kicad_pcb, TG4x.sch]
2019-03-26 replaced pro micro with stm32
    [TG4x.sch]
2019-03-27 updated schematic, added all switch footprints
    [TG4x.kicad_pcb, TG4x.sch, tg4x_all_layout.dxf]
2019-04-21 More Work
    Finished schematic, started pcb footprints, updated annotations, new netlist
    [TG4x.kicad_pcb, TG4x.sch]
2019-04-22 removed hotswap sockets
    no linger going to use hotswap sockets, they don't work with all the layouts.
    [TG4x.kicad_pcb, _saved_TG4x.sch]
2019-04-30 v2 release
    [TG4x-B.Cu.gbr, TG4x-B.Mask.gbr, TG4x-B.SilkS.gbr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]
2019-04-30 added plates
    [bottom_plate.kicad_pcb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]
2019-04-30 gerber files
    [TG4x-B.Cu.gbr, TG4x-B.Mask.gbr, TG4x-B.SilkS.gbr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]
2019-04-30 switch plate changes
    [switch_plate-B.Cu.gbr, switch_plate-B.Mask.gbr, switch_plate-B.SilkS.gbr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]
2019-05-02 release for v2.0
    [TG4x-B.Cu.gbr, TG4x-B.Mask.gbr, TG4x-B.SilkS.gbr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]
2019-05-03 organized files, yay
    [TG4x.kicad_pcb, switch_plate.dxf, tg4x_all_layout.dxf]
2019-05-14 updated for interest check
    [TG4x-B.Cu.gbr, TG4x-B.Mask.gbr, TG4x-B.SilkS.gbr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]
2019-05-15 updated gerbers, added pic
    [switch_plate-B.Cu.gbr, switch_plate-B.Mask.gbr, switch_plate-B.SilkS.gbr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]
2019-05-20 new gerbers
    [TG4x-B.Cu.gbr, TG4x-B.Mask.gbr, TG4x-B.SilkS.gbr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]
2019-05-29 minor aesthetic changes
    [TG4x-B.Cu.gbr, TG4x-B.Mask.gbr, TG4x-B.SilkS.gbr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]
2019-05-29 Updated LED footprint
    [TG4x-B.Cu.gbr, TG4x-B.Mask.gbr, TG4x-B.SilkS.gbr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]
